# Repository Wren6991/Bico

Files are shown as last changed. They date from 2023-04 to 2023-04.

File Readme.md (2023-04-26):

# Bico

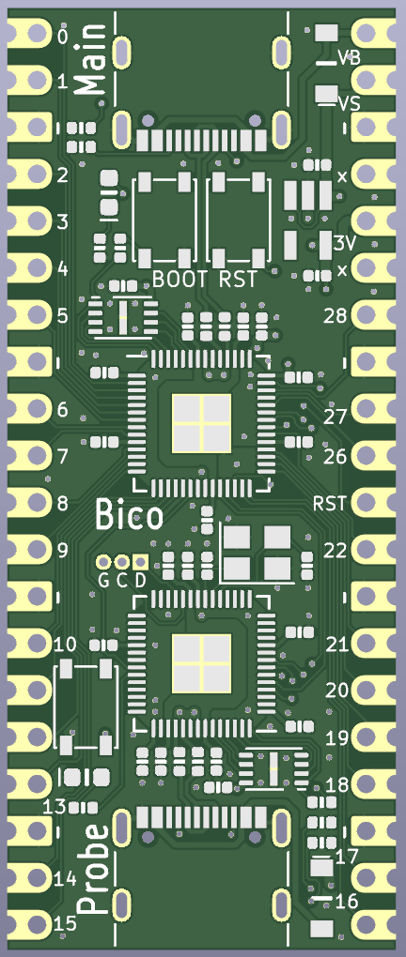
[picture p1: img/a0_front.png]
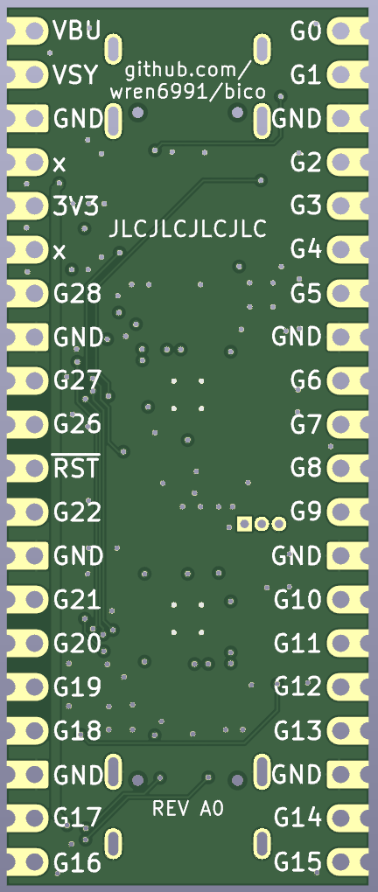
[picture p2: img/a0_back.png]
 

A Pico-shaped board with two RP2040s and two USB sockets. One of the RP2040s does everything you would normally expect from a Pico, while the other provides a debug probe interface for the main RP2040. SWD and UART are connected directly between the two RP2040s on-board, so there are no flying wires required.

The board can be powered from either USB socket. One socket provides USB access to the main RP2040, and the other one provides debug and serial access via the probe RP2040. You can plug in both at the same time, though ideally on the same machine as this will short the grounds and shields of the two USB cables together.

Both RP2040s have BOOTSEL buttons for loading firmware over USB. The main RP2040 also has a reset button.

Schematic is [here](board/bico.pdf) (PDF link)

License: CC0

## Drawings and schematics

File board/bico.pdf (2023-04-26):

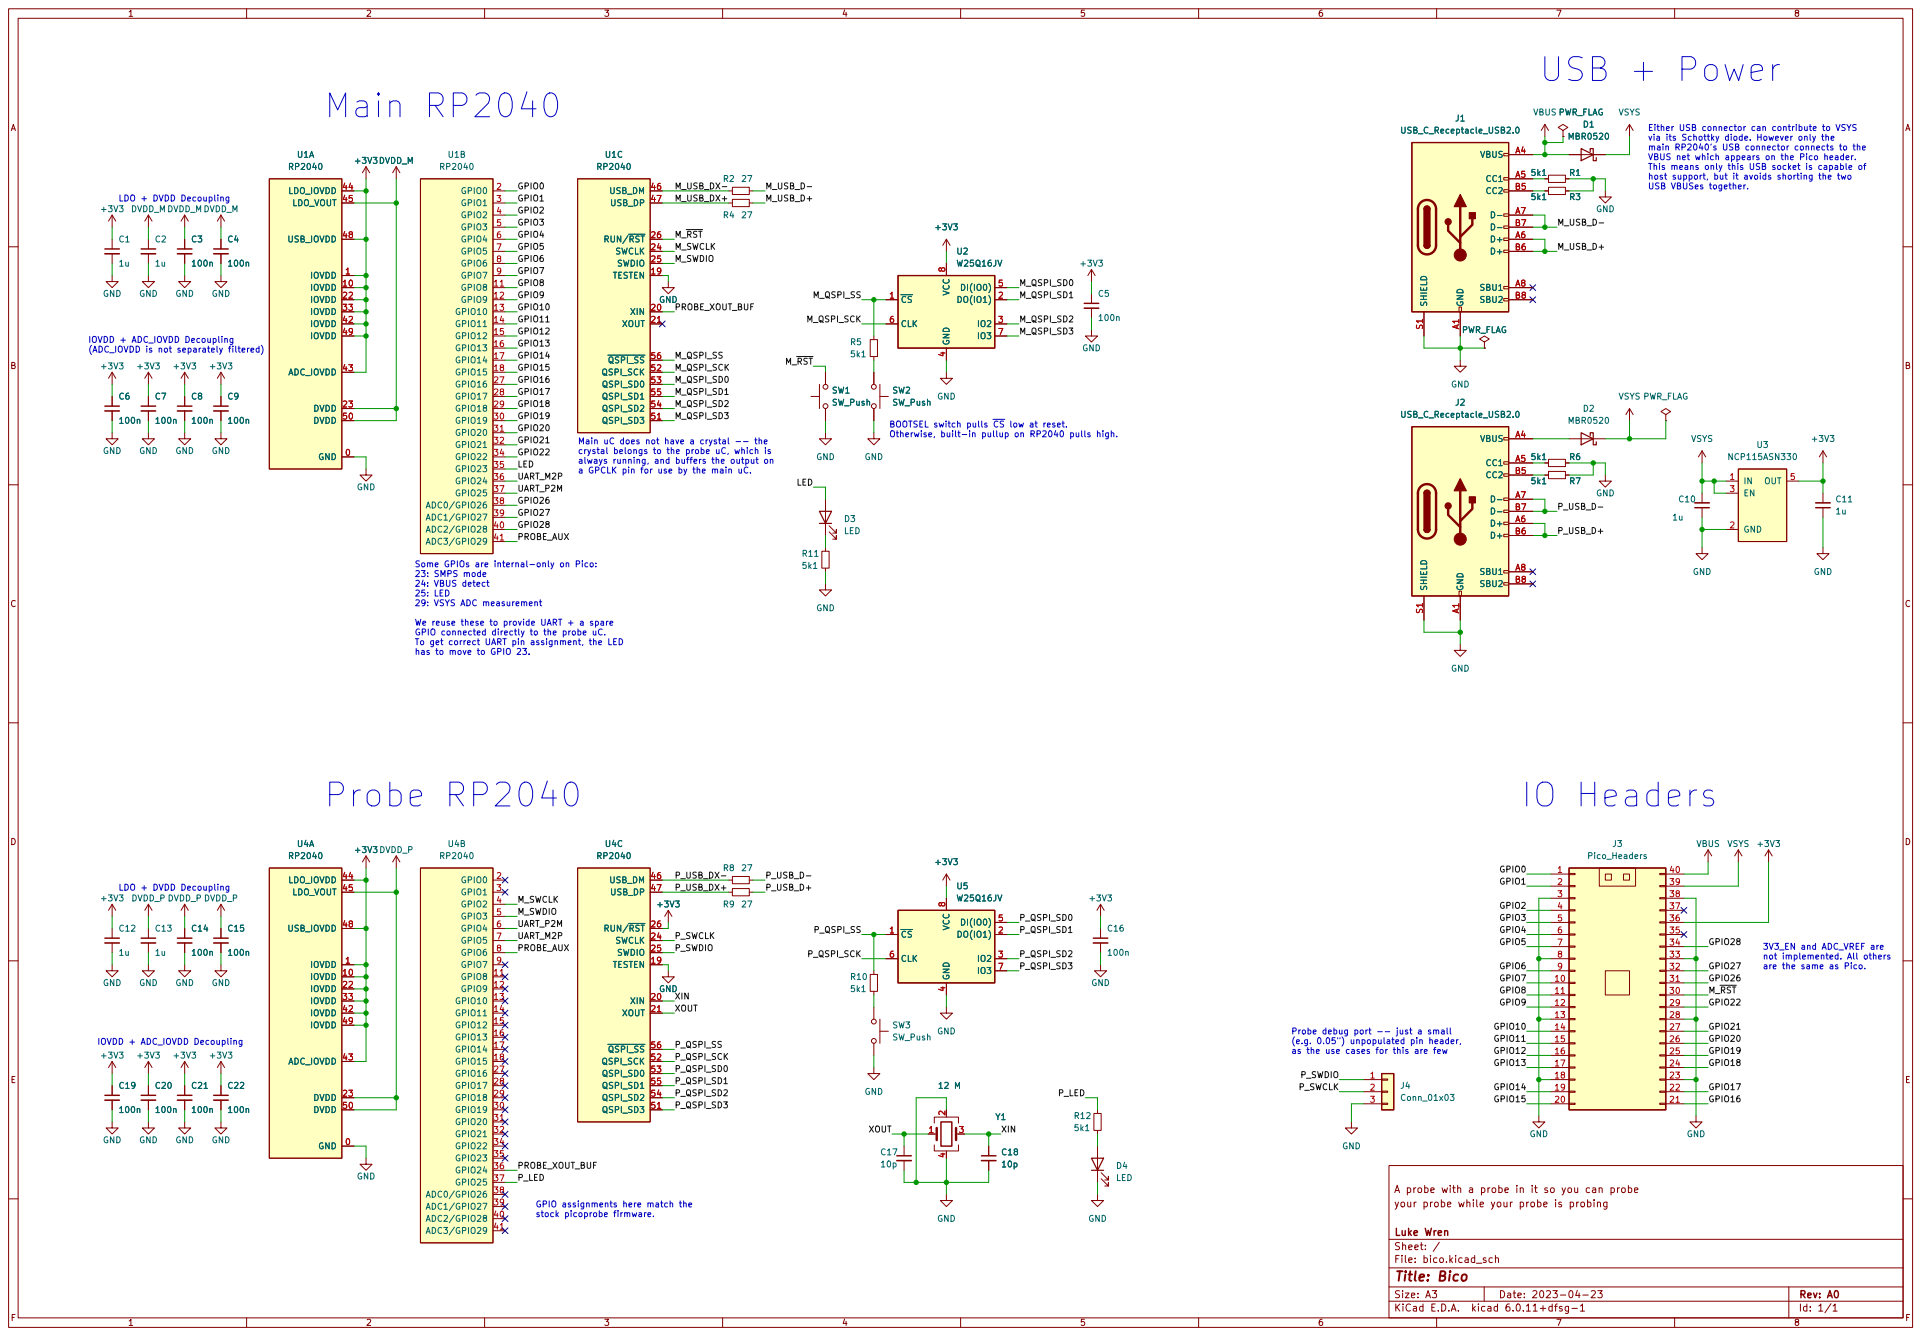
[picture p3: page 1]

crystal belongs to the probe uC, which is always running, and buffers the output on

has to move to GPIO 23.

8 | 33
9 | 32

12 | 29
13 | 28
14 | 27
15 | 26
16 | 25
17 | 24
18 | 23
19 | 22
20 | 21

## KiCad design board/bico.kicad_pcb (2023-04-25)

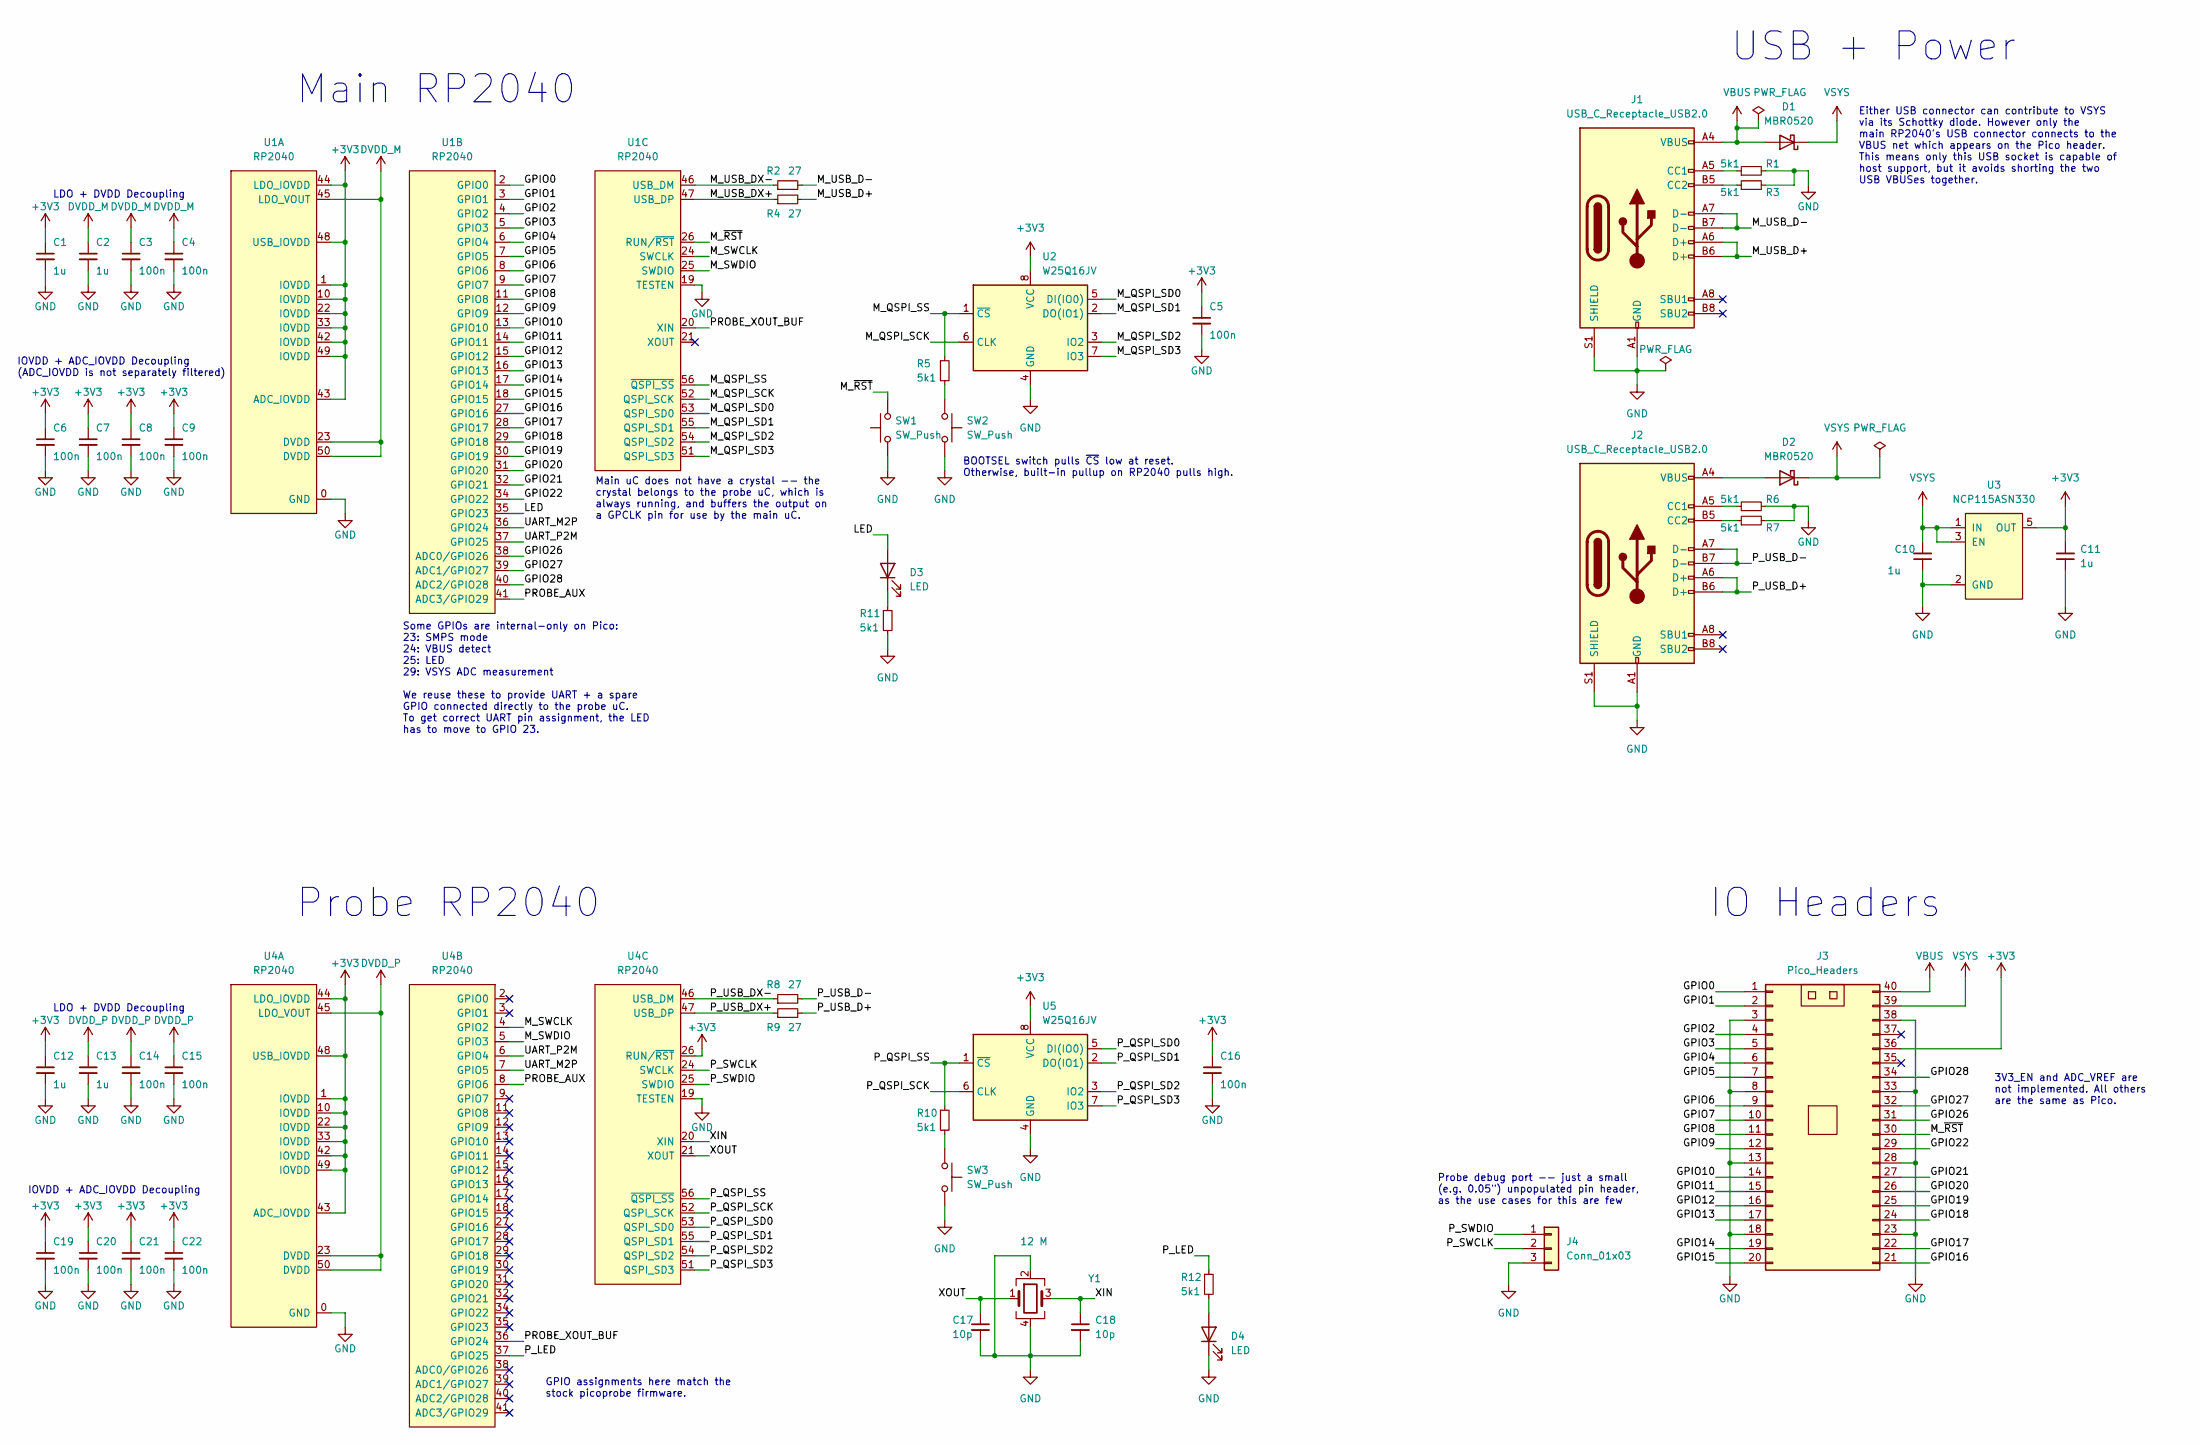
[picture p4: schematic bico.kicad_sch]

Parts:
C1, C2, C10, C11, C12, C13: 1u; C_0402_1005Metric
C3, C4, C5, C6, C7, C8, C9, C14, C15, C16, C19, C20, C21, C22: 100n; C_0402_1005Metric
C17, C18: 10p; C_0402_1005Metric
D1, D2: MBR0520; D_SOD-123
D3, D4: LED; LED_0603_1608Metric
J1, J2: USB_C_Receptacle_USB2.0; USB_C_Receptacle_GCT_USB4105-xx-A_16P_TopMnt_Horizontal
J3: Pico_Headers
J4: Conn_01x03; PinHeader_1x03_P1.00mm_Vertical
R1, R3, R5, R6, R7, R10, R11, R12: 5k1; R_0402_1005Metric
R2, R4, R8, R9: 27; R_0402_1005Metric
SW1, SW2, SW3: SW_Push; SW_SPST_PTS815
U1, U4: RP2040; QFN-56_EP_7x7_Pitch0.4mm
U2, U5: W25Q16JV; DFN-8-3x2mm-Winbond
U3: NCP115ASN330; SOT-23-5_HandSoldering
Y1: 12 M; Crystal_SMD_3225-4Pin_3.2x2.5mm

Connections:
+3V3: C1.1, C5.1, C6.1, C7.1, C8.1, C9.1, C11.2, C12.1, C16.1, C19.1, C20.1, C21.1, C22.1, J3.36, U1.1 (IOVDD), U1.10 (IOVDD), U1.22 (IOVDD), U1.33 (IOVDD), U1.42 (IOVDD), U1.43 (ADC_IOVDD), U1.44 (LDO_IOVDD), U1.48 (USB_IOVDD), U1.49 (IOVDD), U2.8 (VCC), U3.5 (OUT), U4.1 (IOVDD), U4.10 (IOVDD), U4.22 (IOVDD), U4.26 (RUN/~RST), U4.33 (IOVDD), U4.42 (IOVDD), U4.43 (ADC_IOVDD), U4.44 (LDO_IOVDD), U4.48 (USB_IOVDD), U4.49 (IOVDD), U5.8 (VCC)
/GPIO0: J3.1, U1.2 (GPIO0)
/GPIO1: J3.2, U1.3 (GPIO1)
/GPIO2: J3.4, U1.4 (GPIO2)
/GPIO3: J3.5, U1.5 (GPIO3)
/GPIO4: J3.6, U1.6 (GPIO4)
/GPIO5: J3.7, U1.7 (GPIO5)
/GPIO6: J3.9, U1.8 (GPIO6)
/GPIO7: J3.10, U1.9 (GPIO7)
/GPIO8: J3.11, U1.11 (GPIO8)
/GPIO9: J3.12, U1.12 (GPIO9)
/GPIO10: J3.14, U1.13 (GPIO10)
/GPIO11: J3.15, U1.14 (GPIO11)
/GPIO12: J3.16, U1.15 (GPIO12)
/GPIO13: J3.17, U1.16 (GPIO13)
/GPIO14: J3.19, U1.17 (GPIO14)
/GPIO15: J3.20, U1.18 (GPIO15)
/GPIO16: J3.21, U1.27 (GPIO16)
/GPIO17: J3.22, U1.28 (GPIO17)
/GPIO18: J3.24, U1.29 (GPIO18)
/GPIO19: J3.25, U1.30 (GPIO19)
/GPIO20: J3.26, U1.31 (GPIO20)
/GPIO21: J3.27, U1.32 (GPIO21)
/GPIO22: J3.29, U1.34 (GPIO22)
/GPIO26: J3.31, U1.38 (ADC0/GPIO26)
/GPIO27: J3.32, U1.39 (ADC1/GPIO27)
/GPIO28: J3.34, U1.40 (ADC2/GPIO28)
/LED: D3.2 (A), U1.35 (GPIO23)
/M_QSPI_SCK: U1.52 (QSPI_SCK), U2.6 (CLK)
/M_QSPI_SD0: U1.53 (QSPI_SD0), U2.5 (DI(IO0))
/M_QSPI_SD1: U1.55 (QSPI_SD1), U2.2 (DO(IO1))
/M_QSPI_SD2: U1.54 (QSPI_SD2), U2.3 (IO2)
/M_QSPI_SD3: U1.51 (QSPI_SD3), U2.7 (IO3)
/M_QSPI_SS: R5.1, U1.56 (~QSPI_SS), U2.1 (~CS)
/M_SWCLK: U1.24 (SWCLK), U4.4 (GPIO2)
/M_SWDIO: U1.25 (SWDIO), U4.5 (GPIO3)
/M_USB_D+: J1.A6 (D+), J1.B6 (D+), R4.2
/M_USB_D-: J1.A7 (D-), J1.B7 (D-), R2.2
/M_USB_DX+: R4.1, U1.47 (USB_DP)
/M_USB_DX-: R2.1, U1.46 (USB_DM)
/M_~RST: J3.30, SW1.1, U1.26 (RUN/~RST)
/PROBE_AUX: U1.41 (ADC3/GPIO29), U4.8 (GPIO6)
/PROBE_XOUT_BUF: U1.20 (XIN), U4.36 (GPIO24)
/P_LED: R12.1, U4.37 (GPIO25)
/P_QSPI_SCK: U4.52 (QSPI_SCK), U5.6 (CLK)
/P_QSPI_SD0: U4.53 (QSPI_SD0), U5.5 (DI(IO0))
/P_QSPI_SD1: U4.55 (QSPI_SD1), U5.2 (DO(IO1))
/P_QSPI_SD2: U4.54 (QSPI_SD2), U5.3 (IO2)
/P_QSPI_SD3: U4.51 (QSPI_SD3), U5.7 (IO3)
/P_QSPI_SS: R10.1, U4.56 (~QSPI_SS), U5.1 (~CS)
/P_SWCLK: J4.2, U4.24 (SWCLK)
/P_SWDIO: J4.1, U4.25 (SWDIO)
/P_USB_D+: J2.A6 (D+), J2.B6 (D+), R9.2
/P_USB_D-: J2.A7 (D-), J2.B7 (D-), R8.2
/P_USB_DX+: R9.1, U4.47 (USB_DP)
/P_USB_DX-: R8.1, U4.46 (USB_DM)
/UART_M2P: U1.36 (GPIO24), U4.7 (GPIO5)
/UART_P2M: U1.37 (GPIO25), U4.6 (GPIO4)
/XIN: C18.1, U4.20 (XIN), Y1.3
/XOUT: C17.1, U4.21 (XOUT), Y1.1
DVDD_M: C2.1, C3.1, C4.1, U1.23 (DVDD), U1.45 (LDO_VOUT), U1.50 (DVDD)
DVDD_P: C13.1, C14.1, C15.1, U4.23 (DVDD), U4.45 (LDO_VOUT), U4.50 (DVDD)
GND: C1.2, C2.2, C3.2, C4.2, C5.2, C6.2, C7.2, C8.2, C9.2, C10.1, C11.1, C12.2, C13.2, C14.2, C15.2, C16.2, C17.2, C18.2, C19.2, C20.2, C21.2, C22.2, D4.1 (K), J1.A1 (GND), J1.A12 (GND), J1.B1 (GND), J1.B12 (GND), J1.S1 (SHIELD), J2.A1 (GND), J2.A12 (GND), J2.B1 (GND), J2.B12 (GND), J2.S1 (SHIELD), J3.3, J3.8, J3.13, J3.18, J3.23, J3.28, J3.33, J3.38, J4.3, R1.2, R3.2, R6.2, R7.2, R11.2, SW1.2, SW2.1, SW3.2, U1.0 (GND), U1.19 (TESTEN), U2.4 (GND), U3.2 (GND), U4.0 (GND), U4.19 (TESTEN), U5.4 (GND), Y1.2, Y1.4
unnamed: D2.2 (A), J2.A4 (VBUS), J2.A9 (VBUS), J2.B4 (VBUS), J2.B9 (VBUS)
unnamed: D3.1 (K), R11.1
unnamed: J1.A5 (CC1), R1.1
unnamed: J1.B5 (CC2), R3.1
unnamed: J2.A5 (CC1), R6.1
unnamed: J2.B5 (CC2), R7.1
unnamed: R5.2, SW2.2
unnamed: R10.2, SW3.1
unnamed: D4.2 (A), R12.2
VBUS: D1.2 (A), J1.A4 (VBUS), J1.A9 (VBUS), J1.B4 (VBUS), J1.B9 (VBUS), J3.40
VSYS: C10.2, D1.1 (K), D2.1 (K), J3.39, U3.1 (IN), U3.3 (EN)

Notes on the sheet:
Main uC does not have a crystal -- the crystal belongs to the probe uC, which is always running, and buffers the output on a GPCLK pin for use by the main uC.
IOVDD + ADC_IOVDD Decoupling (ADC_IOVDD is not separately filtered)
LDO + DVDD Decoupling
3V3_EN and ADC_VREF are not implemented. All others are the same as Pico.
USB + Power
Probe RP2040
Probe debug port -- just a small (e.g. 0.05") unpopulated pin header, as the use cases for this are few
Some GPIOs are internal-only on Pico: 23: SMPS mode 24: VBUS detect 25: LED 29: VSYS ADC measurement We reuse these to provide UART + a spare GPIO connected directly to the probe uC. To get correct UART pin assignment, the LED has to move to GPIO 23.
GPIO assignments here match the stock picoprobe firmware.
IO Headers
Either USB connector can contribute to VSYS via its Schottky diode. However only the main RP2040's USB connector connects to the VBUS net which appears on the Pico header. This means only this USB socket is capable of host support, but it avoids shorting the two USB VBUSes together.
IOVDD + ADC_IOVDD Decoupling
BOOTSEL switch pulls ~{CS} low at reset. Otherwise, built-in pullup on RP2040 pulls high.
Main RP2040

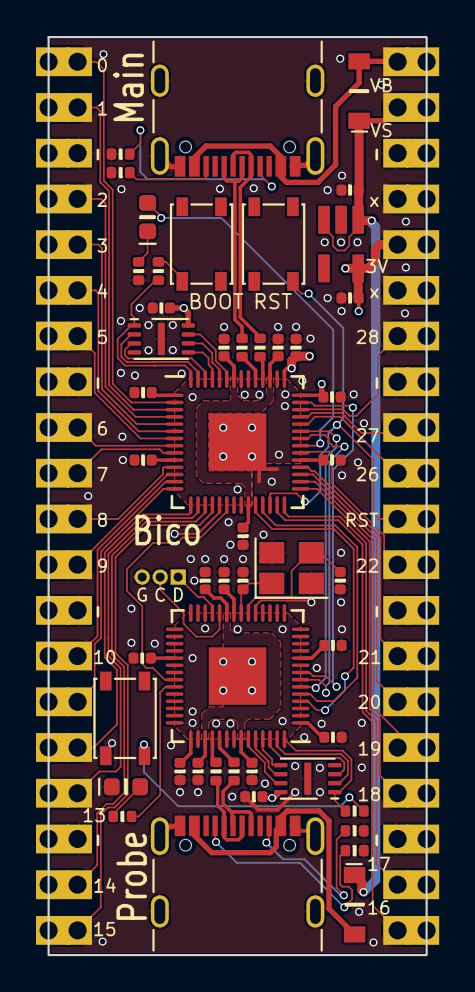
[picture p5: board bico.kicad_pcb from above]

Board: 4 copper layers, 21.0 x 51.0 mm, 51 parts (0 on the bottom side), 74 nets.

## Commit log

2023-04-23 Initial commit, very rough schematic sketched in
    [bico.kicad_pcb, bico.kicad_sch]
2023-04-23 ERC clean. Split RP2040 DVDDs, and add LEDs and probe debug header
    [bico.kicad_sch]
2023-04-23 Assign footprints
    [bico.kicad_sch]
2023-04-23 Rough initial placement
    [bico.kicad_pcb, bico.kicad_sch]
2023-04-25 Start routing
    [bico.kicad_pcb, bico.kicad_sch]
2023-04-25 Fully routed
    [bico.kicad_pcb, bico.kicad_sch]
2023-04-25 DRC clean, for now
    [bico.kicad_pcb]
2023-04-25 Tidy up grounding etc
    [bico.kicad_pcb]
2023-04-25 Label all pins in silkscreen
    [bico.kicad_pcb, bico.kicad_sch]
2023-04-25 Add github link and silk text to board underside
    [bico.kicad_pcb]
2023-04-25 Add JLC silk text
    [bico.kicad_pcb]
2023-04-26 Add generated files and readme
    [bico-B_Cu.gbl, bico-B_Mask.gbs, bico-B_Paste.gbp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]
